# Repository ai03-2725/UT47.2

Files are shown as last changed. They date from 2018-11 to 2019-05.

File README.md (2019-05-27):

# UT47.2
Hot-swappable 40% Keyboard PCB

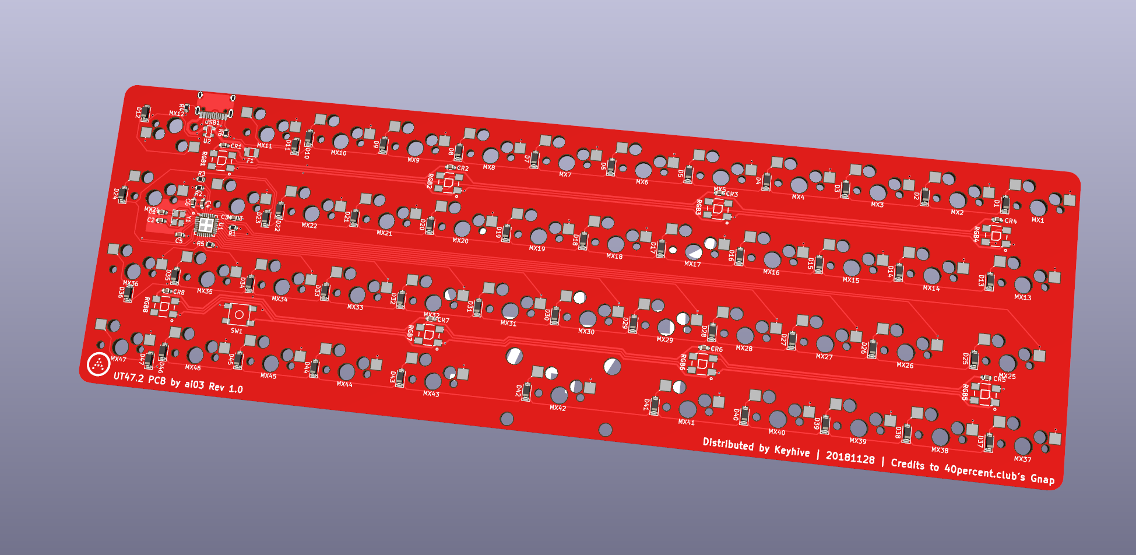
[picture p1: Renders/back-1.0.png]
Render


#### In light of recent claims that I am 100% liable for any of my open source PCBs, I am adding this disclaimer.
#### I provide these PCBs as a reference for designing keyboard PCBs. Using them within your projects will require a will to do research of one's own and to learn the workings of them, potentially fixing issues if they exist.
# I provide these PCBs without liability and without any guarantees regarding functionality, as expressed in the MIT license under which all of these PCBs are licensed.

Keyboard Layout Editor layout: [Layout](http://www.keyboard-layout-editor.com/#/gists/ddc8fda154c2c93ac26e38cd5da5988e)

An open-source commission for [KeyHive](https://keyhive.xyz/).

The design is inspired by 40percent.club's Gnap keyboard, which is licensed under [CC BY-SA 4.0](https://creativecommons.org/licenses/by-sa/4.0/).



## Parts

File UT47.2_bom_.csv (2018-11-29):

Component | Description | Part | References | Value | Footprint | Quantity Per PCB | Datasheet
1 | Unpolarized capacitor | C_Small | C4 C5 CR1 CR2 CR3 CR4 CR5 CR6 CR7 CR8 | 0.1u | C_0603 | 10
2 | Unpolarized capacitor | C_Small | C3 | 1uF | C_0603 | 1
3 | Unpolarized capacitor | C_Small | C1 C2 | 22p | C_0603 | 2
4 | Unpolarized capacitor | C_Small | C6 | 4.7u | C_0603 | 1
5 | Diode, small symbol | D_Small | D1 D2 D3 D4 D5 D6 D7 D8 D9 D10 D11 D12 D13 D14 D15 D16 D17 D18 D19 D20 D21 D22 D23 D24 D25 D26 D27 D28 D29 D30 D31 D32 D33 D34 D35 D36 D37 D38 D39 D40 D41 D42 D43 D44 D45 D46 D47 | SOD-123 | D_SOD-123 | 47 | ~
6 | resettable fuse, polymeric positive temperature coefficient (PPTC), small symbol | Polyfuse_Small | F1 | 500mA | Fuse_SMD1206_Reflow | 1
7 |  | MX-1U | MX13 MX24 MX41 MX43 | MX-1.25U | MXOnly-1.25U-Hotswap | 4
8 |  | MX-1U | MX12 MX25 | MX-1.5U | MXOnly-1.5U-Hotswap | 2
9 |  | MX-1U | MX1 MX2 MX3 MX4 MX5 MX6 MX7 MX8 MX9 MX10 MX11 MX14 MX15 MX16 MX17 MX18 MX19 MX20 MX21 MX22 MX23 MX26 MX27 MX28 MX29 MX30 MX31 MX32 MX33 MX34 MX35 MX36 MX37 MX38 MX39 MX40 MX44 MX45 MX46 MX47 | MX-1U | MXOnly-1U-Hotswap | 40
10 |  | MX-1U | MX42 | MX-2U | MXOnly-2U-Hotswap-ReversedStabilizers | 1
11 | Resistor, small symbol | R_Small | R1 R5 | 10k | R_0603 | 2
12 | Resistor, small symbol | R_Small | R2 R3 | 22 | R_0603 | 2
13 | Resistor, small symbol | R_Small | R4 R6 | 5.1k | R_0603 | 2
14 |  | WS2812B | RGB1 RGB2 RGB3 RGB4 RGB5 RGB6 RGB7 RGB8 | WS2812B | WS2812B | 8
15 |  | SW_PUSH | SW1 | SW_PUSH | SKQG-1155865 | 1
16 |  | ATMEGA32U2-AU | U1 | ATMEGA32U2-AU | QFN-32-1EP_5x5mm_Pitch0.5mm | 1 | http://www.atmel.com/Images/doc7799.pdf
17 |  | PRTR5V0U2X | U2 | PRTR5V0U2X | SOT143B | 1
18 |  | HRO-TYPE-C-31-M-12 | USB1 | HRO-TYPE-C-31-M-12 | HRO-TYPE-C-31-M-12-Assembly | 1
19 | Four pin crystal, two ground/package pins (pin2 and 4) small symbol | Crystal_GND24_Small | Y1 | 16MHz | Crystal_SMD_3225-4pin_3.2x2.5mm | 1
Component Groups: | 19
Component Count: | 128
Fitted Components: | 128
Number of PCBs: | 1
Total components: | 128
Schematic Version:
Schematic Date:
BoM Date: | 11/28/2018 21:01
Schematic Source: | UT47.2.sch
KiCad Version: | Eeschema (5.0.0)

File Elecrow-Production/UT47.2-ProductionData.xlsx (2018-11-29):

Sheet: PCB Specification
UT47.2 Keyboard PCB Specification
PCB Quantity | 50pcs
Layer | 2layer
PCB Thickness | 1.6mm
Dimensions | 238mm * 76mm
Castellated Hole | No
PCB Color | Black
Surface Finish | HASL With Lead
Copper Weight | 1oz
Text Color | White
Different Design | 1
Please find more PCB information on our on-line PCB ordering Page
https://www.elecrow.com/pcb-manufacturing.html

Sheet: BOM
UT47.2 Keyboard PCB
# | References | Quantity Per PCB | Value | Package | Manufacturer Part number | Description | SMD | THT | Original | Elecrow PN | Note
1 | C4 C5 CR1 CR2 CR3 CR4 CR5 CR6 CR7 CR8 | 10 | 0.1u | C_0603 | 478-9926-1-ND | Ceramic Capacitor | 20 |  | N |  | 16V Minimum, X5R or X7R
2 | C3 | 1 | 1uF | C_0603 | 490-4785-1-ND | Ceramic Capacitor | 2 |  | N |  | 16V Minimum, X5R or X7R
3 | C1 C2 | 2 | 22p | C_0603 | 1276-2605-1-ND | Ceramic Capacitor | 4 |  | N |  | 16V Minimum, C0G
4 | C6 | 1 | 4.7u | C_0603 | 1276-1784-1-ND | Ceramic Capacitor | 2 |  | N |  | 16V Minimum, X5R or X7R
5 | D1 D2 D3 D4 D5 D6 D7 D8 D9 D10 D11 D12 D13 D14 D15 D16 D17 D18 D19 D20 D21 D22 D23 D24 D25 D26 D27 D28 D29 D30 D31 D32 D33 D34 D35 D36 D37 D38 D39 D40 D41 D42 D43 D44 D45 D46 D47 | 47 | SOD-123 | D_SOD-123 | BAV21W-FDICT-ND | Diode, SOD-123, Generic | 94 |  | N
6 | F1 | 1 | 500mA | Fuse_SMD1206_Reflow | F3733CT-ND | Polyfuse, 500mA hold, 1A trip, 1206 | 2 |  | N |  | 10V Minimum
7 | MX13 MX24 MX41 MX43 | 4 | MX-1.25U | MXOnly-1.25U-Hotswap | PG151101S11 | Kailh MX Switch Hotswap Sockets | 8 |  | Y
8 | MX12 MX25 | 2 | MX-1.5U | MXOnly-1.5U-Hotswap | PG151101S11 | Kailh MX Switch Hotswap Sockets | 4 |  | Y
9 | MX1 MX2 MX3 MX4 MX5 MX6 MX7 MX8 MX9 MX10 MX11 MX14 MX15 MX16 MX17 MX18 MX19 MX20 MX21 MX22 MX23 MX26 MX27 MX28 MX29 MX30 MX31 MX32 MX33 MX34 MX35 MX36 MX37 MX38 MX39 MX40 MX44 MX45 MX46 MX47 | 40 | MX-1U | MXOnly-1U-Hotswap | PG151101S11 | Kailh MX Switch Hotswap Sockets | 80 |  | Y
10 | MX42 | 1 | MX-2U | MXOnly-2U-Hotswap-ReversedStabilizers | PG151101S11 | Kailh MX Switch Hotswap Sockets | 2 |  | Y
11 | R1 R5 | 2 | 10k | R_0603 | MCT0603-10.0K-CFCT-ND | Resistor | 4 |  | N |  | 1/8W Minimum
12 | R2 R3 | 2 | 22 | R_0603 | MCT0603-22.0-CFCT-ND | Resistor | 4 |  | N |  | 1/8W Minimum
13 | R4 R6 | 2 | 5.1k | R_0603 | RHM5.1KDCT-ND | Resistor | 4 |  | N |  | 1/8W Minimum
14 | RGB1 RGB2 RGB3 RGB4 RGB5 RGB6 RGB7 RGB8 | 8 | WS2812B | WS2812B | C114586 | WS2812B RGB LED, 5050 | 32 |  | N |  | https://lcsc.com/product-detail/Light-Emitting-Diodes-LED_5050-RGBIntegrated-Light-4Pin_C114586.html
15 | SW1 | 1 | SW_PUSH | SKQG-1155865 | SKQGADE010 | Push button, 5.2 x 5.2mm | 4 |  | N
16 | U1 | 1 | ATMEGA32U2-MU | QFN-32-1EP_5x5mm_Pitch0.5mm | ATMEGA32U2-MU-ND | Atmel ATMEGA32U2-MU, QFN-32 | 32 |  | Y
17 | U2 | 1 | PRTR5V0U2X | SOT143B | 1727-3884-1-ND | ESD Protection Chip | 4 |  | Y
18 | USB1 | 1 | HRO-TYPE-C-31-M-12 | HRO-TYPE-C-31-M-12-Assembly | C165948 | HRO USB connector | 12 | 4 | Y |  | https://lcsc.com/product-detail/USB-Type-C_Korean-Hroparts-Elec-TYPE-C-31-M-12_C165948.html
19 | Y1 | 1 | 16MHz | Crystal_SMD_3225-4pin_3.2x2.5mm | X1E000021037500 | Crystal, 16MHz, 8-10pF load capacitance, 3.2 x 2.5mm | 4 |  | N
 |  |  |  |  |  |  | 318 | 4
 | Declare：
 | 1、If the component should be original like Digi-key or Mouser，the component must have complete Manufacture part number

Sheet: Parts Mapping
Please see Layout.pdf

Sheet: Position File
Switch sockets in UT47.2-socket.pos
Other parts in UT47.2-bottom.pos

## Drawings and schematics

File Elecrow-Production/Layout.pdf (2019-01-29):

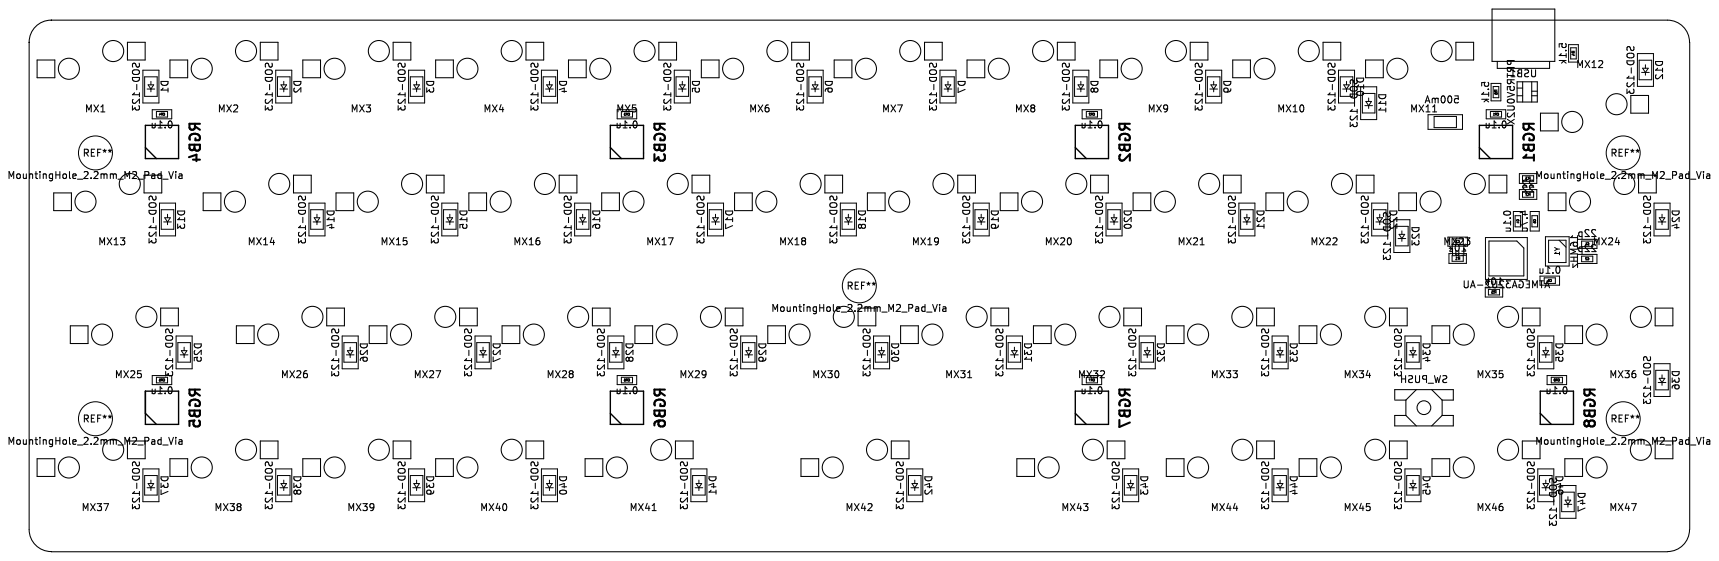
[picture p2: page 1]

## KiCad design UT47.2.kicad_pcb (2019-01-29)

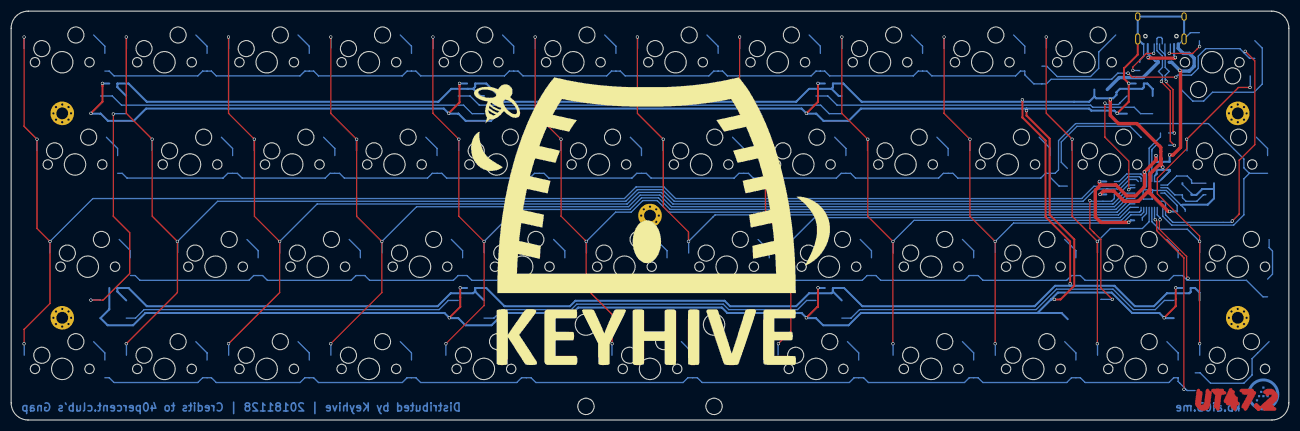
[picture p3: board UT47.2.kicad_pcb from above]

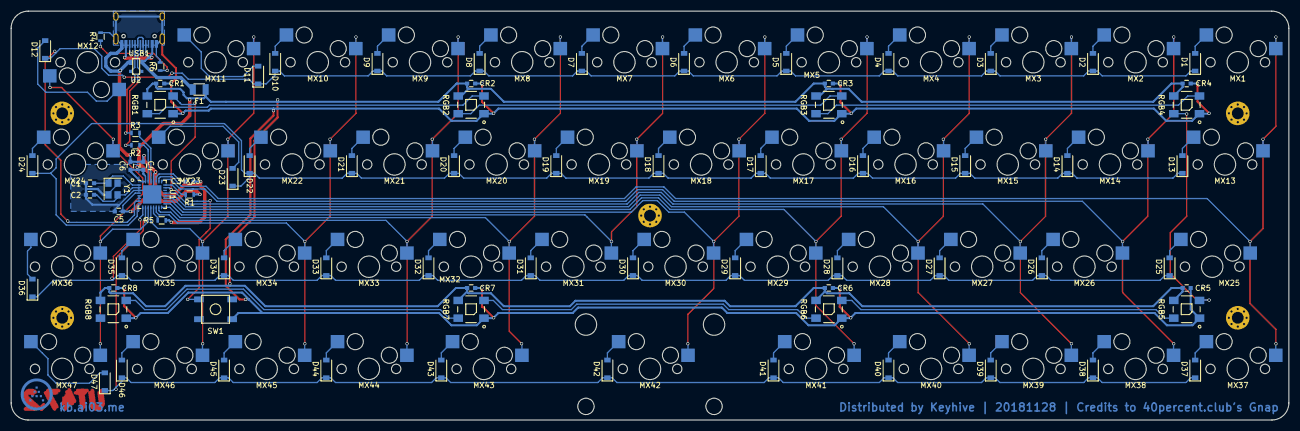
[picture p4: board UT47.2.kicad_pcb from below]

Board: 2 copper layers, 238.1 x 76.2 mm, 128 parts (81 on the bottom side), 85 nets.

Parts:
C1, C2: 22p; C_0603
C3: 1uF; C_0603
C4, C5: 0.1u; C_0603
C6: 4.7u; C_0603
CR1, CR2, CR3, CR4, CR5, CR6, CR7, CR8: 0.1u; C_0603
D1, D2, D3, D4, D5, D6, D7, D8, D9, D10, D11, D12, D13, D14, D15, D16, D17, D18, D19, D20, D21, D22, D23, D24, D25, D26, D27, D28, D29, D30, D31, D32, D33, D34, D35, D36, D37, D38, D39, D40, D41, D42, D43, D44, D45, D46, D47: SOD-123; D_SOD-123
F1: 500mA; Fuse_SMD1206_Reflow
MX1, MX2, MX3, MX4, MX5, MX6, MX7, MX8, MX9, MX10, MX11, MX14, MX15, MX16, MX17, MX18, MX19, MX20, MX21, MX22, MX23, MX26, MX27, MX28, MX29, MX30, MX31, MX32, MX33, MX34, MX35, MX36, MX37, MX38, MX39, MX40, MX44, MX45, MX46, MX47: MX-1U; MXOnly-1U-Hotswap
MX12, MX25: MX-1.5U; MXOnly-1.5U-Hotswap
MX13, MX24, MX41, MX43: MX-1.25U; MXOnly-1.25U-Hotswap
MX42: MX-2U; MXOnly-2U-Hotswap-ReversedStabilizers
R1, R5: 10k; R_0603
R2, R3: 22; R_0603
R4, R6: 5.1k; R_0603
RGB1, RGB2, RGB3, RGB4, RGB5, RGB6, RGB7, RGB8: VAL**; WS2812B
SW1: SW_PUSH; SKQG-1155865
U1: ATMEGA32U2-AU; QFN-32-1EP_5x5mm_Pitch0.5mm
U2: PRTR5V0U2X; SOT143B
USB1: HRO-TYPE-C-31-M-12; HRO-TYPE-C-31-M-12-Assembly
Y1: 16MHz; Crystal_SMD_3225-4pin_3.2x2.5mm

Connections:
+5V: C4.1, C5.1, C6.1, CR1.1, CR2.1, CR3.1, CR4.1, CR5.1, CR6.1, CR7.1, CR8.1, F1.1, R1.1, RGB1.1, RGB2.1, RGB3.1, RGB4.1, RGB5.1, RGB6.1, RGB7.1, RGB8.1, U1.4, U1.31, U1.32
COL0: MX1.1, MX13.1, MX25.1, MX37.1, U1.26
COL1: MX2.1, MX14.1, MX26.1, MX38.1, U1.25
COL2: MX3.1, MX15.1, MX27.1, MX39.1, U1.21
COL3: MX4.1, MX16.1, MX28.1, MX40.1, U1.20
COL4: MX5.1, MX17.1, MX29.1, MX41.1, U1.19
COL5: MX6.1, MX18.1, MX30.1, MX42.1, U1.18
COL6: MX7.1, MX19.1, MX31.1, U1.17
COL7: MX8.1, MX20.1, MX32.1, MX43.1, U1.16
COL8: MX9.1, MX21.1, MX33.1, MX44.1, U1.15
COL9: MX10.1, MX22.1, MX34.1, MX45.1, U1.14
COL10: MX11.1, MX23.1, MX35.1, MX46.1, U1.12
COL11: MX12.1, MX24.1, MX36.1, MX47.1, U1.11
D+: R3.2, U1.29
D-: R2.1, U1.30
GND: C1.2, C2.2, C3.2, C4.2, C5.2, C6.2, CR1.2, CR2.2, CR3.2, CR4.2, CR5.2, CR6.2, CR7.2, CR8.2, R4.2, R5.1, R6.2, RGB1.3, RGB2.3, RGB3.3, RGB4.3, RGB5.3, RGB6.3, RGB7.3, RGB8.3, SW1.1, U1.3, U1.28, U2.1, USB1.1, USB1.12, USB1.13, Y1.2, Y1.4
unnamed: C1.1, U1.1, Y1.1
unnamed: C2.1, U1.2, Y1.3
unnamed: C3.1, U1.27
unnamed: D1.2, MX1.2
unnamed: D2.2, MX2.2
unnamed: D3.2, MX3.2
unnamed: D4.2, MX4.2
unnamed: D5.2, MX5.2
unnamed: D6.2, MX6.2
unnamed: D7.2, MX7.2
unnamed: D8.2, MX8.2
unnamed: D9.2, MX9.2
unnamed: D10.2, MX10.2
unnamed: D11.2, MX11.2
unnamed: D12.2, MX12.2
unnamed: D13.2, MX13.2
unnamed: D14.2, MX14.2
unnamed: D15.2, MX15.2
unnamed: D16.2, MX16.2
unnamed: D17.2, MX17.2
unnamed: D18.2, MX18.2
unnamed: D19.2, MX19.2
unnamed: D20.2, MX20.2
unnamed: D21.2, MX21.2
unnamed: D22.2, MX22.2
unnamed: D23.2, MX23.2
unnamed: D24.2, MX24.2
unnamed: D25.2, MX25.2
unnamed: D26.2, MX26.2
unnamed: D27.2, MX27.2
unnamed: D28.2, MX28.2
unnamed: D29.2, MX29.2
unnamed: D30.2, MX30.2
unnamed: D31.2, MX31.2
unnamed: D32.2, MX32.2
unnamed: D33.2, MX33.2
unnamed: D34.2, MX34.2
unnamed: D35.2, MX35.2
unnamed: D36.2, MX36.2
unnamed: D37.2, MX37.2
unnamed: D38.2, MX38.2
unnamed: D39.2, MX39.2
unnamed: D40.2, MX40.2
unnamed: D41.2, MX41.2
unnamed: D42.2, MX42.2
unnamed: D43.2, MX43.2
unnamed: D44.2, MX44.2
unnamed: D45.2, MX45.2
unnamed: D46.2, MX46.2
unnamed: D47.2, MX47.2
unnamed: R1.2, SW1.2, U1.24
unnamed: R2.2, U2.3, USB1.5, USB1.7
unnamed: R3.1, U2.2, USB1.6, USB1.8
unnamed: R4.1, USB1.10
unnamed: R5.2, U1.13
unnamed: R6.1, USB1.4
unnamed: RGB1.2, RGB2.4
unnamed: RGB2.2, RGB3.4
unnamed: RGB3.2, RGB4.4
unnamed: RGB4.2, RGB5.4
unnamed: RGB5.2, RGB6.4
unnamed: RGB6.2, RGB7.4
unnamed: RGB7.2, RGB8.4
RGBLED: RGB1.4, U1.23
ROW0: D1.1, D2.1, D3.1, D4.1, D5.1, D6.1, D7.1, D8.1, D9.1, D10.1, D11.1, D12.1, U1.7
ROW1: D13.1, D14.1, D15.1, D16.1, D17.1, D18.1, D19.1, D20.1, D21.1, D22.1, D23.1, D24.1, U1.8
ROW2: D25.1, D26.1, D27.1, D28.1, D29.1, D30.1, D31.1, D32.1, D33.1, D34.1, D35.1, D36.1, U1.9
ROW3: D37.1, D38.1, D39.1, D40.1, D41.1, D42.1, D43.1, D44.1, D45.1, D46.1, D47.1, U1.10
VCC: F1.2, U2.4, USB1.2, USB1.11

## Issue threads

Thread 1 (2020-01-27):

Wrong part name for the Atmega-chip

Kyrremann, 2020-01-27:
`ATMEGA32U2-AU` is listed in the BOM-list, but they are all QNP, it should rather list `ATMEGA32U2-MU` which is the QNF equivalent.

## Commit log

2018-11-29 Add necessary files based on Voyager 60:
    [Matrix.sch, Mir.kicad_pcb, Mir.sch]
2018-11-29 Update to kicad5
    [Matrix-2018-11-28-17-00-06.sch, Mir-2018-11-28-17-00-06.sch, Mir.sch]
2018-11-29 Route without MCU connections
    [Matrix.sch, Mir.kicad_pcb, Mir.sch]
2018-11-29 Finish routing
    [Mir.kicad_pcb, Mir.sch]
2018-11-29 Error check
    [Mir.kicad_pcb]
2018-11-29 Add corner indicators for RGBs
    [Mir.kicad_pcb]
2018-11-29 Rename project
    [UT47.2-B.Cu.gbl, UT47.2-B.Mask.gbs, UT47.2-B.SilkS.gbo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]
2018-11-29 Fix position files
    [UT47.2-B.Cu.gbl, UT47.2-B.Mask.gbs, UT47.2-B.SilkS.gbo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]
2018-11-29 Final tweaks
    [UT47.2-B.Cu.gbl, UT47.2-B.Mask.gbs, UT47.2-B.SilkS.gbo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]
2018-11-29 Finally get KiCad to print properly
    [UT47.2-ProductionData.xlsx, UT47.2.kicad_pcb]
2018-11-29 Partially complete production data
    [UT47.2-ProductionData.xlsx]
2018-11-29 Finish production spreadsheet
    [UT47.2-B.Cu.gbl, UT47.2-B.Mask.gbs, UT47.2-B.SilkS.gbo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]
2018-11-29 Adjust a bit of silkscreen
    [UT47.2-B.Cu.gbl, UT47.2-B.Mask.gbs, UT47.2-B.SilkS.gbo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]
2019-01-06 Annotate overall dimensions in mm
    [UT47.2.kicad_pcb]
2019-01-07 Build generic case files
    [UT47.2-Bottom.kicad_pcb, UT47.2-Bottom.sch, UT47.2-Top.kicad_pcb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]
2019-01-29 Update with drill holes
    [UT47.2-B.Cu.gbl, UT47.2-B.Mask.gbs, UT47.2-B.Paste.gbp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]
2019-01-29 New case data
    [UT47.2-Bottom-B.Cu.gbl, UT47.2-Bottom-B.Mask.gbs, UT47.2-Bottom-B.SilkS.gbo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]
2019-01-29 Rename gerber

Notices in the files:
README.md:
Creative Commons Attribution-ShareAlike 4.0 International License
